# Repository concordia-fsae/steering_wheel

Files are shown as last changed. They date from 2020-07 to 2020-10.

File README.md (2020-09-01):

### This code now has Travis CI setup for continuous integration testing!
Current build status: 

# Setup Instructions
  1. Setup PlatformIO in IDE of choice (i.e. VSCode)
  2. Navigate to PlatformIO install directory (usually User_folder/.platformio)
  3. Enter `packages` directory and rename `framework-arduinoststm32-maple` to `framework-arduinoststm32-maple-bak`
  4. Clone [Roger Clark's repo](https://github.com/rogerclarkmelbourne/Arduino_STM32) into the packages directory (`git clone https://github.com/rogerclarkmelbourne/Arduino_STM32.git framework-arduinoststm32-maple`)
  5. Copy `platformio-build-stm32f4.py` and `platformio-build-stm32f1.py` from `framework-arduinoststm32-maple-bak/tools` to `framework-arduinoststm32-maple/tools`
  6. Compile successfully (hopefully)

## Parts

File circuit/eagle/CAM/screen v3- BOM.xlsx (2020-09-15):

Items | Part | Part number | Value | Quantity needed | Quantity bought | Unit price | Total Price
1 | Crystal | Q1 | 8MHz | 1 | -
2 | Capacitor | C3, C2 | 22PF | 2 | -
3 | Capacitor | C4 | 0.1uF | 1 | -
4 | Resisor | R2 | 10K | 1 | -
5 | Resisor | R3 | 120R | 1 | -
6 | canbus module | MCP2515-I/SO | n/a | 1 | -
7 |  | TJA1050 | n/a | 1 | -
8 | screen | NHD-4.3RTP | n/a | 1 | -
9 | JST connector | JST-XH-05-PACKAGE-ROUND-PAD | 5 pin CNCT | 1 | -
10 | stm 32 | stm32 | n/a | 1 | -
11 | JST connector | JST-XH-05-PACKAGE-ROUND-PAD | 5 pin CNCT | 1 | -
12 | LED | WS2812B_THT_ROUND |  | 16 | -
13

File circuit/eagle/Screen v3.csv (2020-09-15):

Part | Value | Device | Package | Description | AVAILABILITY | DESCRIPTION | MF | MP | MPN | OC_FARNELL | OC_NEWARK | PACKAGE | PRICE | SPICEPREFIX
BTN3 |  | SMD5 | SMD2,54-5,08 | SMD PAD
BTN4 |  | SMD5 | SMD2,54-5,08 | SMD PAD
BTN5 |  | SMD5 | SMD2,54-5,08 | SMD PAD
C2 | 22PF | C-EUC0805 | C0805 | CAPACITOR, European symbol |  |  |  |  |  |  |  |  |  | C
C3 | 22PF | C-EUC0805 | C0805 | CAPACITOR, European symbol |  |  |  |  |  |  |  |  |  | C
C4 | 0.1uF | C-EUC0805 | C0805 | CAPACITOR, European symbol |  |  |  |  |  |  |  |  |  | C
CANH |  | SMD5 | SMD2,54-5,08 | SMD PAD
CANL |  | SMD5 | SMD2,54-5,08 | SMD PAD
CSMCP |  | SMD5 | SMD2,54-5,08 | SMD PAD
DIN |  | SMD5 | SMD2,54-5,08 | SMD PAD
GND |  | SMD5 | SMD2,54-5,08 | SMD PAD
GND@1 |  | SMD5 | SMD2,54-5,08 | SMD PAD
GND@2 |  | SMD5 | SMD2,54-5,08 | SMD PAD
GND@3 | val\ | SMD5 | SMD2,54-5,08 | SMD PAD
MCPINT |  | SMD5 | SMD2,54-5,08 | SMD PAD
MISO |  | SMD5 | SMD2,54-5,08 | SMD PAD
MOSI |  | SMD5 | SMD2,54-5,08 | SMD PAD
Q1 | 8MHz | CRYSTALHC49S | HC49/S | CRYSTAL |  |  |  |  |  | 1667008 | unknown
R2 | 10K | R-EU_M0805 | M0805 | RESISTOR, European symbol |  |  |  |  |  |  |  |  |  | R
R3 | 120R | R-EU_M0805 | M0805 | RESISTOR, European symbol |  |  |  |  |  |  |  |  |  | R
RENC00 |  | SMD5 | SMD2,54-5,08 | SMD PAD
RENC0GND |  | SMD5 | SMD2,54-5,08 | SMD PAD
RENC01 |  | SMD5 | SMD2,54-5,08 | SMD PAD
RENC1GND |  | SMD5 | SMD2,54-5,08 | SMD PAD
RENC10 |  | SMD5 | SMD2,54-5,08 | SMD PAD
RENC11 |  | SMD5 | SMD2,54-5,08 | SMD PAD
SCK |  | SMD5 | SMD2,54-5,08 | SMD PAD
SCREEN | NHD-4.3RTP | NHD-4.3RTP | NHD-4.3RTP | Arduino R3 Footprint with SPI header
SW1 |  | SMD5 | SMD2,54-5,08 | SMD PAD
SW2 |  | SMD5 | SMD2,54-5,08 | SMD PAD
SW4 |  | SMD5 | SMD2,54-5,08 | SMD PAD
SW5 |  | SMD5 | SMD2,54-5,08 | SMD PAD
U$1 |  | STM32F103C8T6DIP40 | STM32
U$2 | MCP2515-I/SO | MCP2515-I/SO | SOIC127P1034X264-18N | CAN Controller | Unavailable | MCP2515 Series 5.5 V 1 Mb/s Stand Alone SPI Interface CAN Controller- SOIC-18 | Microchip | MCP2515-I/SO |  |  |  | SOIC-18 Microchip | None
U1 | TJA1050 | TJA1050 | SOT96-1 | High speed CAN transceiver | Unavailable |  | NXP Semiconductors | TJA1050 |  |  |  | None | None
VCCIN |  | SMD5 | SMD2,54-5,08 | SMD PAD
VCCLEDS |  | SMD5 | SMD2,54-5,08 | SMD PAD
VCCMCP |  | SMD5 | SMD2,54-5,08 | SMD PAD
X1 | 5 pin cnt | JST-XH-05-PIN-ROUND-PAD | JST-XH-05-PACKAGE-ROUND-PAD | JST XH Connector 2 Pin

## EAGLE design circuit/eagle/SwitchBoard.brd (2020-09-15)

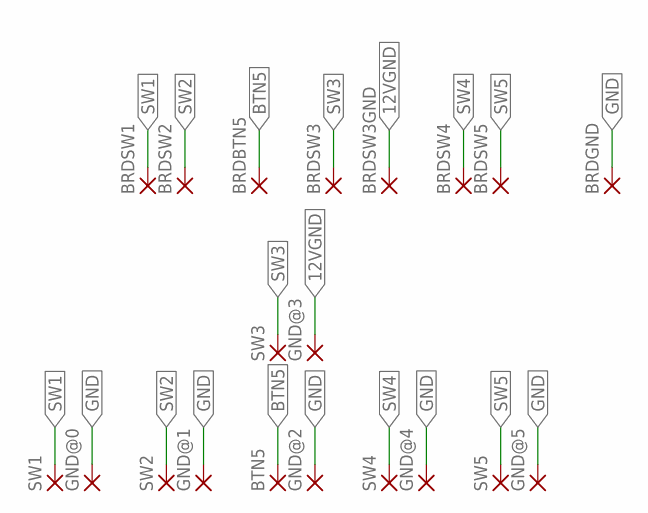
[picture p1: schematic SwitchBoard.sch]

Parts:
BRDBTN5: SMD5; SMD2,54-5,08
BRDGND: SMD5; SMD2,54-5,08
BRDSW1, BRDSW2, BRDSW3, BRDSW3GND, BRDSW4, BRDSW5: SMD5; SMD2,54-5,08
BTN5: SMD5; SMD2,54-5,08
GND@0, GND@1, GND@2, GND@3, GND@4, GND@5: SMD5; SMD2,54-5,08
SW1, SW2, SW3, SW4, SW5: SMD5; SMD2,54-5,08

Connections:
12VGND: BRDSW3GND.1, GND@3.1
BTN5: BRDBTN5.1, BTN5.1
GND: BRDGND.1, GND@0.1, GND@1.1, GND@2.1, GND@4.1, GND@5.1
SW1: BRDSW1.1, SW1.1
SW2: BRDSW2.1, SW2.1
SW3: BRDSW3.1, SW3.1
SW4: BRDSW4.1, SW4.1
SW5: BRDSW5.1, SW5.1

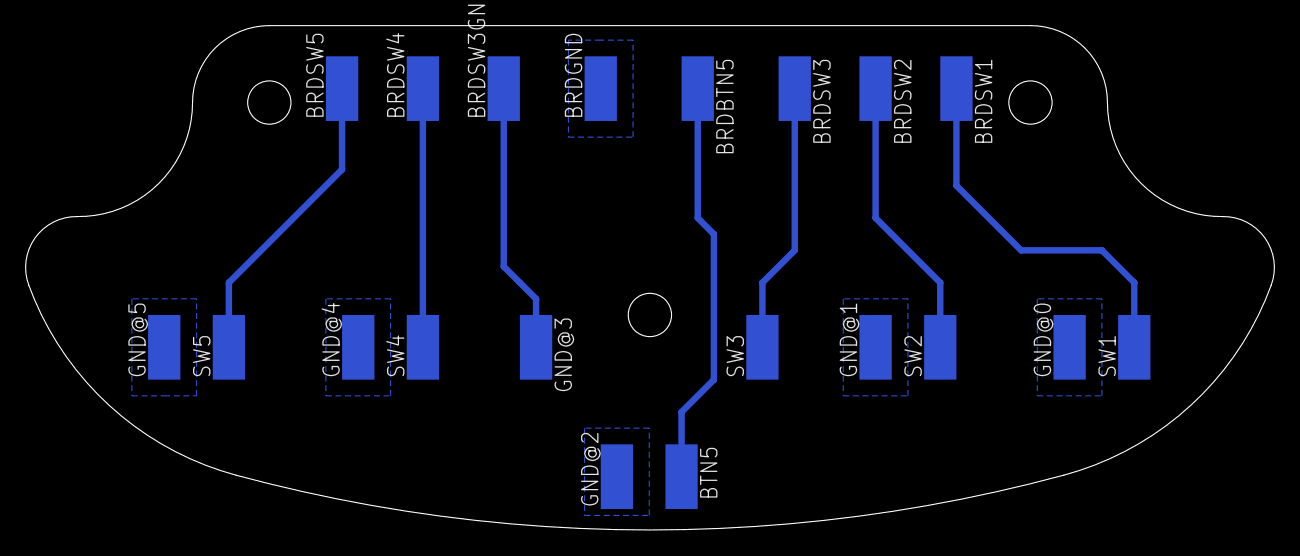
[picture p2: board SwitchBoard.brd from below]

Board: 2 copper layers, 98.1 x 39.6 mm, 20 parts (20 on the bottom side), 8 nets.

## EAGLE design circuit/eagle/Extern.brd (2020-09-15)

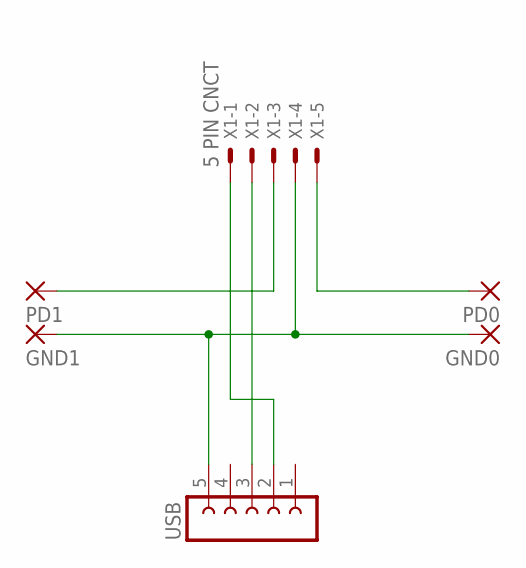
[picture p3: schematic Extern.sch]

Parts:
GND0, GND1: SMD5; SMD2,54-5,08
PD0, PD1: SMD5; SMD2,54-5,08
USB: FE05-1
X1: 5 PIN CNCT; JST-XH-05-PACKAGE-ROUND-PAD

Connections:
D+: USB.3, X1.2
D-: USB.2, X1.1
GND: GND0.1, GND1.1, USB.5, X1.4
unnamed: PD0.1, X1.5
PD1: PD1.1, X1.3

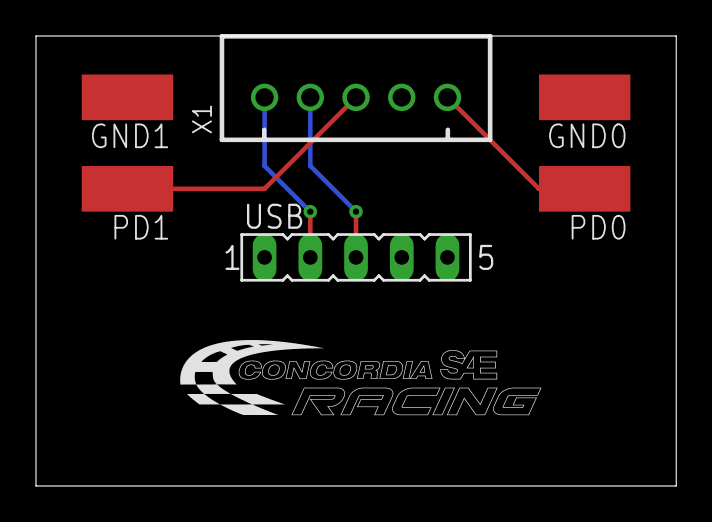
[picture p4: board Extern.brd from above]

Board: 2 copper layers, 35.6 x 25.0 mm, 6 parts (0 on the bottom side), 5 nets.

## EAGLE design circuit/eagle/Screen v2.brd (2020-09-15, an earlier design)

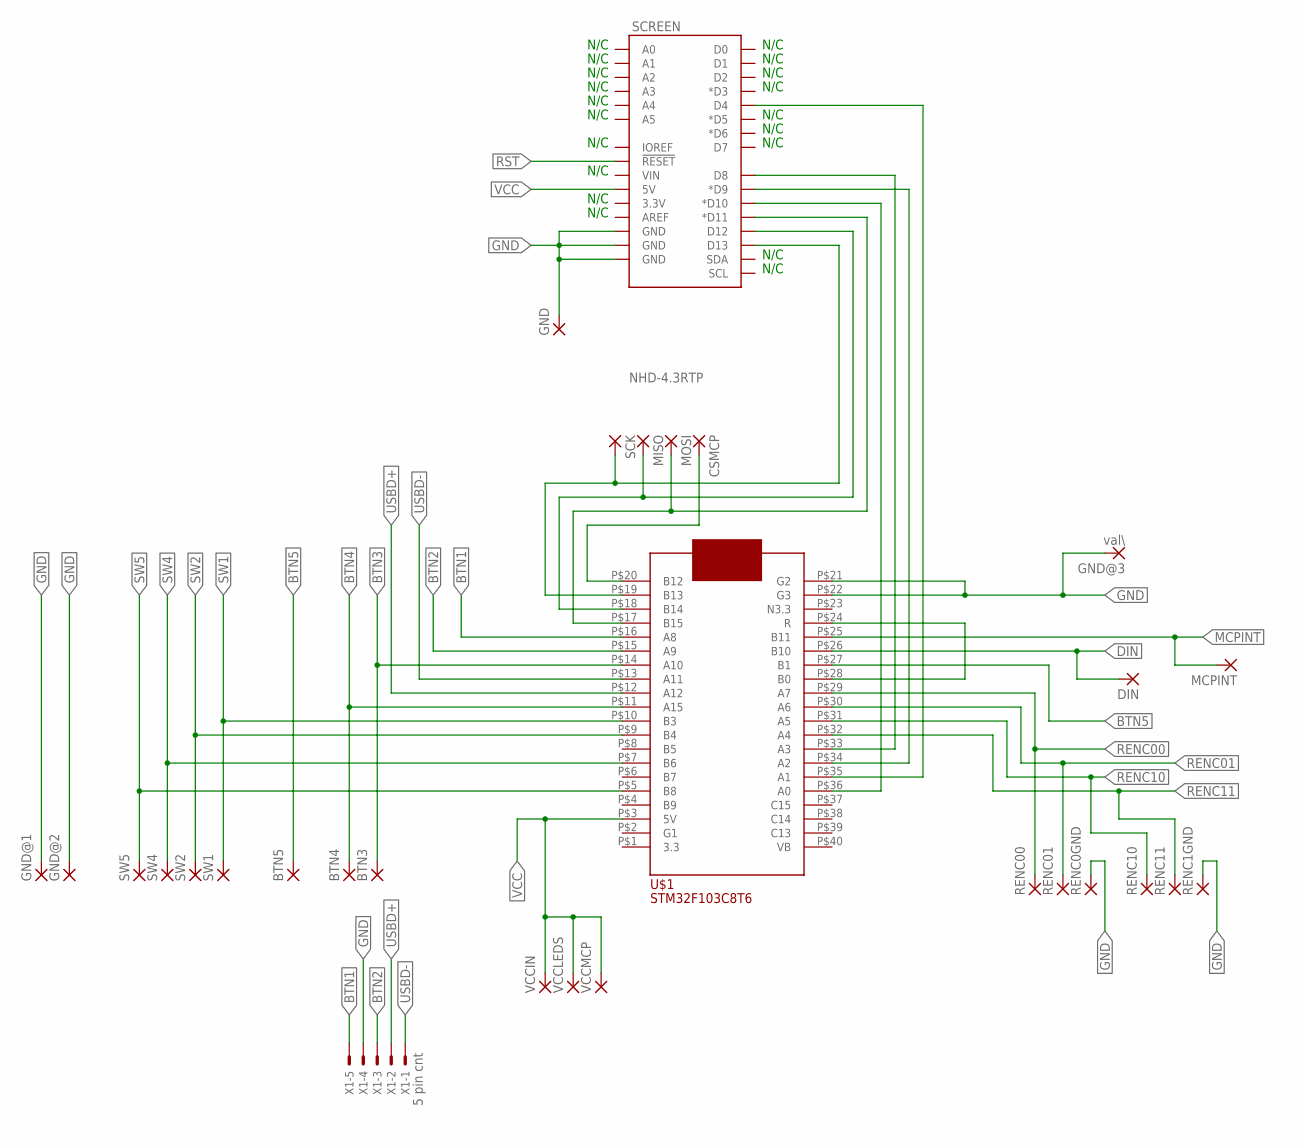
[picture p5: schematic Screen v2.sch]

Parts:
BTN3, BTN4, BTN5: SMD5; SMD2,54-5,08
CSMCP: SMD5; SMD2,54-5,08
DIN: SMD5; SMD2,54-5,08
GND: SMD5; SMD2,54-5,08
GND@1, GND@2: SMD5; SMD2,54-5,08
GND@3: val\; SMD2,54-5,08
MCPINT: SMD5; SMD2,54-5,08
MISO: SMD5; SMD2,54-5,08
MOSI: SMD5; SMD2,54-5,08
RENC00, RENC0GND, RENC01, RENC1GND, RENC10, RENC11: SMD5; SMD2,54-5,08
SCK: SMD5; SMD2,54-5,08
SCREEN: NHD-4.3RTP
SW1, SW2, SW4, SW5: SMD5; SMD2,54-5,08
U$1: STM32F103C8T6DIP40; STM32
VCCIN: SMD5; SMD2,54-5,08
VCCLEDS: SMD5; SMD2,54-5,08
VCCMCP: SMD5; SMD2,54-5,08
X1: 5 pin cnt; JST-XH-05-PACKAGE-ROUND-PAD

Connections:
BTN1: U$1.P$16 (A8), X1.5
BTN2: U$1.P$15 (A9), X1.3
BTN3: BTN3.1, U$1.P$14 (A10)
BTN4: BTN4.1, U$1.P$11 (A15)
BTN5: BTN5.1, U$1.P$27 (B1)
CSMCP: CSMCP.1, U$1.P$20 (B12)
CS_SCREEN: SCREEN.D10 (*D10), U$1.P$36 (A0)
DIN: DIN.1, U$1.P$26 (B10)
GND: GND.1, GND@1.1, GND@2.1, GND@3.1, RENC0GND.1, RENC1GND.1, SCREEN.GND@1 (GND), SCREEN.GND@2 (GND), SCREEN.GND@3 (GND), U$1.P$21 (G2), U$1.P$22 (G3), X1.4
MCPINT: MCPINT.1, U$1.P$25 (B11)
MISO: MISO.1, SCREEN.D12, U$1.P$18 (B14)
MOSI: MOSI.1, SCREEN.D11 (*D11), U$1.P$17 (B15)
unnamed: SCREEN.D4, U$1.P$35 (A1)
unnamed: SCREEN.D9 (*D9), U$1.P$34 (A2)
unnamed: SCREEN.D8, U$1.P$33 (A3)
unnamed: U$1.P$24 (R), U$1.P$28 (B0)
RENC00: RENC00.1, U$1.P$29 (A7)
RENC01: RENC01.1, U$1.P$30 (A6)
RENC10: RENC10.1, U$1.P$31 (A5)
RENC11: RENC11.1, U$1.P$32 (A4)
RST: SCREEN.RESET@1 (!RESET!)
SCK: SCK.1, SCREEN.D13, U$1.P$19 (B13)
SW1: SW1.1, U$1.P$10 (B3)
SW2: SW2.1, U$1.P$9 (B4)
SW4: SW4.1, U$1.P$7 (B6)
SW5: SW5.1, U$1.P$5 (B8)
USBD+: U$1.P$12 (A12), X1.2
USBD-: U$1.P$13 (A11), X1.1
VCC: SCREEN.5V, U$1.P$3 (5V), VCCIN.1, VCCLEDS.1, VCCMCP.1

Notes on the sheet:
N/C

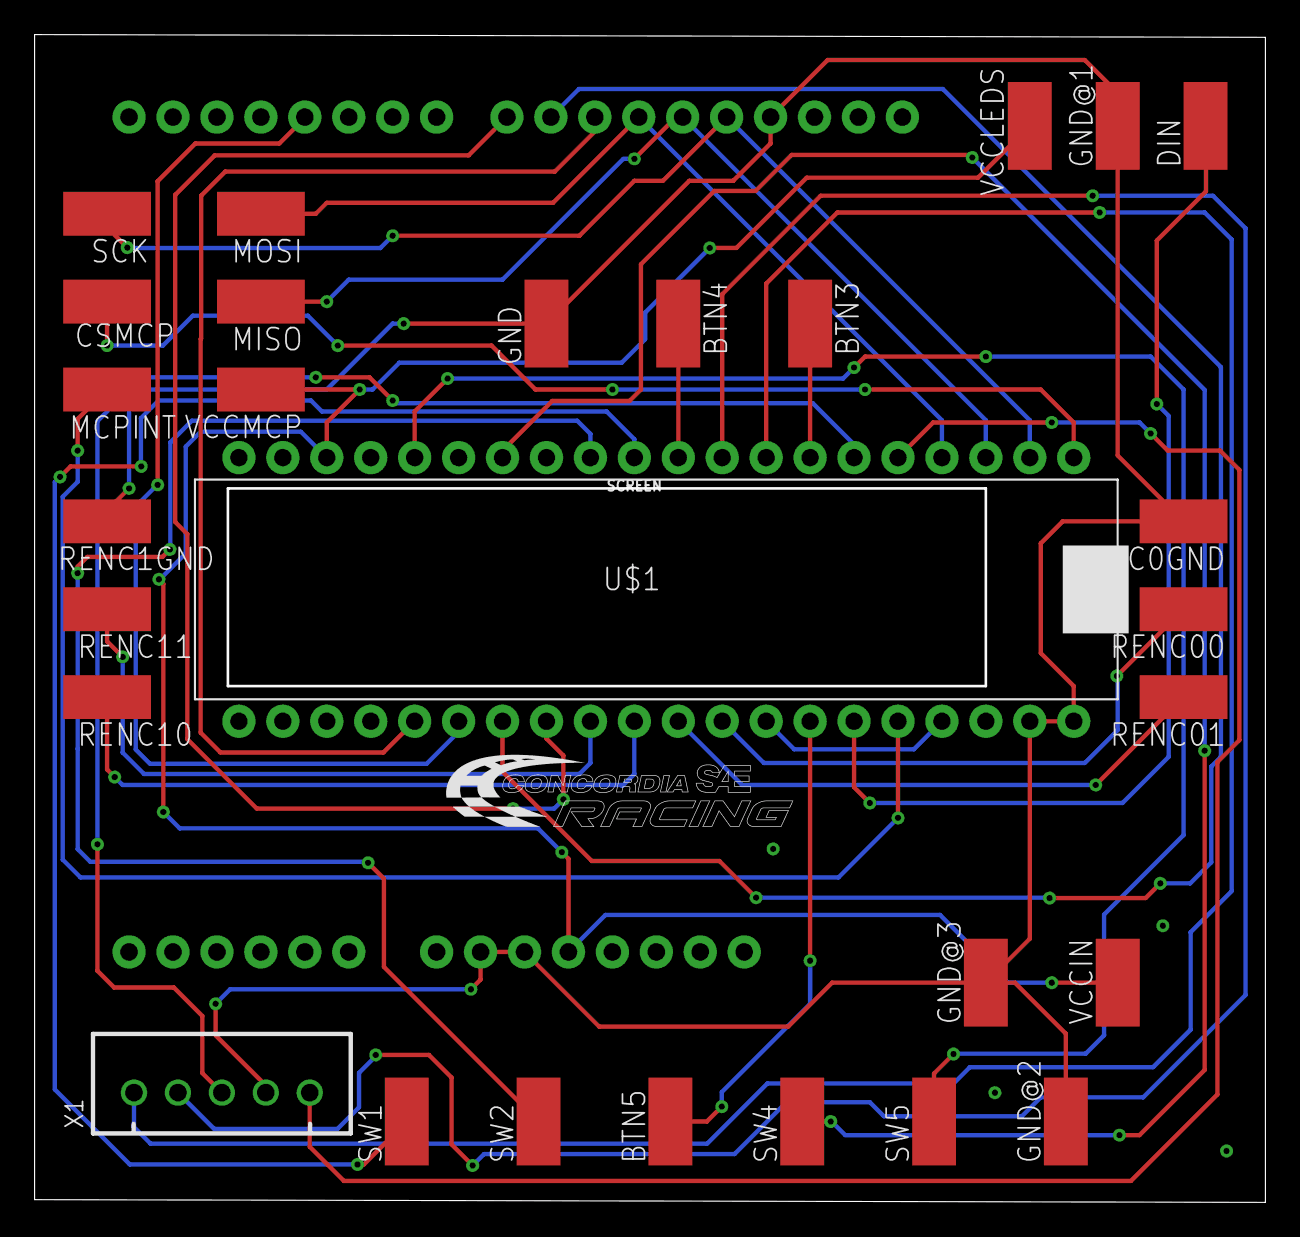
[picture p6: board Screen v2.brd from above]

Board: 2 copper layers, 71.2 x 67.5 mm, 29 parts (0 on the bottom side), 28 nets.

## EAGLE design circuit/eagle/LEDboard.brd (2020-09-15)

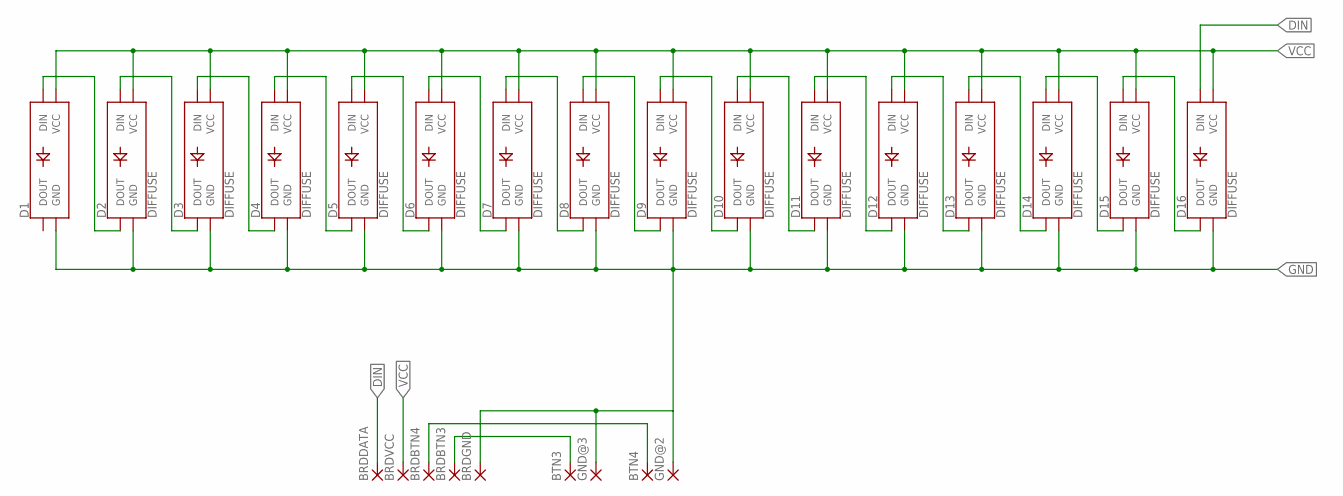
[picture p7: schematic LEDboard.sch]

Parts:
BRDBTN3, BRDBTN4: SMD5; SMD2,54-5,08
BRDDATA: SMD5; SMD2,54-5,08
BRDGND: SMD5; SMD2,54-5,08
BRDVCC: SMD5; SMD2,54-5,08
BTN3, BTN4: SMD5; SMD2,54-5,08
D1: WS2812B_THT_ROUNDDIFFUSE; WS2812B_THT_ROUND
D2, D3, D4, D5, D6, D7, D8, D9, D10, D11, D12, D13, D14, D15, D16: DIFFUSE; WS2812B_THT_ROUND
GND@2, GND@3: SMD5; SMD2,54-5,08

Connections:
BTN3: BRDBTN3.1, BTN3.1
BTN4: BRDBTN4.1, BTN4.1
DIN: BRDDATA.1, D16.1 (DIN)
GND: BRDGND.1, D1.3 (GND), D2.3 (GND), D3.3 (GND), D4.3 (GND), D5.3 (GND), D6.3 (GND), D7.3 (GND), D8.3 (GND), D9.3 (GND), D10.3 (GND), D11.3 (GND), D12.3 (GND), D13.3 (GND), D14.3 (GND), D15.3 (GND), D16.3 (GND), GND@2.1, GND@3.1
unnamed: D15.1 (DIN), D16.4 (DOUT)
unnamed: D14.1 (DIN), D15.4 (DOUT)
unnamed: D13.1 (DIN), D14.4 (DOUT)
unnamed: D12.1 (DIN), D13.4 (DOUT)
unnamed: D11.1 (DIN), D12.4 (DOUT)
unnamed: D10.1 (DIN), D11.4 (DOUT)
unnamed: D9.1 (DIN), D10.4 (DOUT)
unnamed: D8.1 (DIN), D9.4 (DOUT)
unnamed: D7.1 (DIN), D8.4 (DOUT)
unnamed: D6.1 (DIN), D7.4 (DOUT)
unnamed: D5.1 (DIN), D6.4 (DOUT)
unnamed: D4.1 (DIN), D5.4 (DOUT)
unnamed: D3.1 (DIN), D4.4 (DOUT)
unnamed: D2.1 (DIN), D3.4 (DOUT)
unnamed: D1.1 (DIN), D2.4 (DOUT)
VCC: BRDVCC.1, D1.2 (VCC), D2.2 (VCC), D3.2 (VCC), D4.2 (VCC), D5.2 (VCC), D6.2 (VCC), D7.2 (VCC), D8.2 (VCC), D9.2 (VCC), D10.2 (VCC), D11.2 (VCC), D12.2 (VCC), D13.2 (VCC), D14.2 (VCC), D15.2 (VCC), D16.2 (VCC)

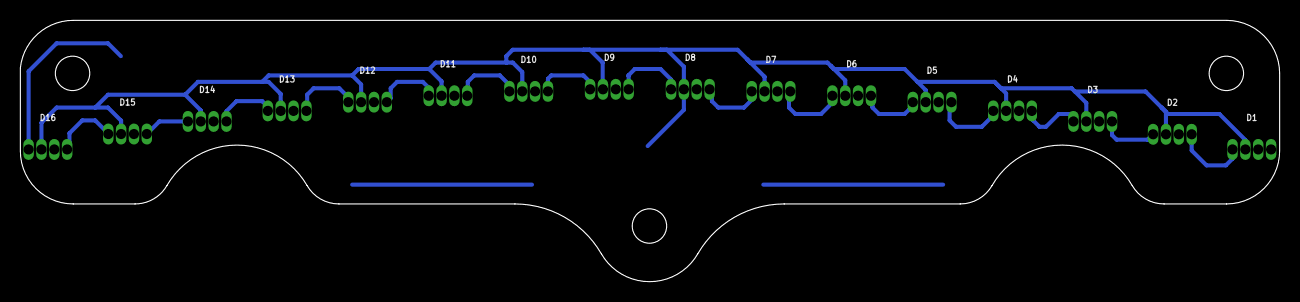
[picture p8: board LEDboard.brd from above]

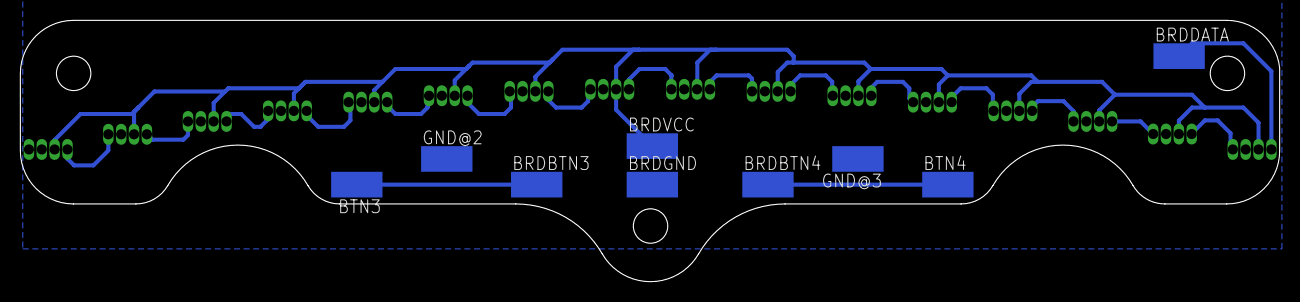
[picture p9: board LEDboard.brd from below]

Board: 2 copper layers, 124.5 x 25.8 mm, 25 parts (9 on the bottom side), 20 nets.

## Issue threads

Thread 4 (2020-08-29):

use direct port access for button status

rickyelopez, 2020-08-29:
Rather than calling digitalRead over and over, pull the data for the whole port and filter out unnecessary values

rickyelopez, 2020-09-01:
issue handled in #10 , closing for now, might re-open once we have access to the cage and can actually test this

Closed 2020-09-01.

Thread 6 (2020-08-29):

implement timer class instead of always comparing numbers

rickyelopez, 2020-08-29:
instead of comparing current time to history over and over, create a timer class that can be queried and updated.

rickyelopez, 2020-09-05:
on hold while I investigate potentially using FreeRTOS

Closed 2020-09-05.

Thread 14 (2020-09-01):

store calibration info in eeprom && make calibration accessible from UI

rickyelopez, 2020-09-01:
Right now all the touchscreen calibration constants are hard-coded and not changeable through software.

1. Store the constants associated with touchscreen calibration in EEPROM
    - can initialize these values with the ones that are currently hard-coded
    - can re-initialize (i.e. if eeprom is ever found to be empty) with the hard-coded values
2. Clean up the calibration routine (read: make the calibration routine actually make sense)
    - make this method callable through code
    - add button to diag page that launches calibration
    - make this method actually store the constants in eeprom
    - add a `#define` and associated method that clears the calibration constants from the eeprom (in case someone badly calibrates the screen and we need to reset it

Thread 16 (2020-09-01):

[potential bug] with displaying common status indicators

rickyelopez, 2020-09-01:
lines 304-323 in screen.h:

```
	col = (tl) ? 0x00FF00 : 0xFFFFFF;
	FTImpl.ColorRGB(col);
	FTImpl.Vertex2ii(20, 35, 1, 0);

	col = (tl) ? 0x00FF00 : 0xFFFFFF;
	FTImpl.ColorRGB(col);
	FTImpl.Vertex2ii(445, 35, 1, 0);

	col = (tl) ? 0x00FF00 : 0xFFFFFF;
	FTImpl.ColorRGB(col);
	FTImpl.Vertex2ii(150, 255, 1, 0);

	col = (tl) ? 0x00FF00 : 0xFFFFFF;
	FTImpl.ColorRGB(col);
	FTImpl.Vertex2ii(210, 255, 1, 0);

	col = (tl) ? 0x00FF00 : 0xFFFFFF;
```

each of these references `tl` but I think each of them should reference a different status var. Can someone check this and see if maybe I'm being silly?

If I'm right, then that means that this codebase is not actually the most recent steering wheel code. No idea where any more recent code might be though, so next time we go out driving we'll have to re-validate that all the functions work :/

rickyelopez, 2020-09-05:
confirmed bug, easy fix

Closed 2020-09-06.

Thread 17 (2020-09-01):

[potential bug] double-check debouncing code for remote-start activation

rickyelopez, 2020-09-01:
in the get_inputs() function, the code that checks if both the top left and top right buttons are pressed is:
```
	if(tl && tr){
		tr_deb = (!tr_deb) ? c_time : tr_deb;
		if(c_time - tr_deb > 500){

			tr_deb = 0;
			remote_start = true;
		}
		tr = tl = false;

	} else {
		remote_start = 0;
		tr_deb = 0;
	}
```

Once we have access to the car and the steering wheel, need to check that this actually works properly.

Closed 2020-09-06.

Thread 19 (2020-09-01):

redesign shifter paddles to use the magnets as buttons

rickyelopez, 2020-09-01:
Instead of having the shifter paddle press down on a little button, attach some wires to the magnets on the paddle and on the paddle base. Then, when the magnets are separated the circuit will be broken, which we can measure! Use that event to trigger shifts.

This change should mean that the entire shifter package can be made more compact and **much** simpler. Plus, assembly will be easier.

- [ ] Add channels for wires to pass through to get to magnets
- [ ] Figure out how to securely connect wires to magents - can we solder? Might break magnets
- [ ] Test changes

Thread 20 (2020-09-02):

fork seeed canbus library and implement as git submodule

rickyelopez, 2020-09-02:
I used [this](https://github.com/Seeed-Studio/CAN_BUS_Shield) library to implement the MCP2515. I had to modify it slightly to get it to work for our use case. Thus, it hasn't been updated from source in literally years. The source has changed quite a bit since then, so it would be nice to rebase to the new code and validate that everything still works. If the modification that I originally made is still necessary, the seeed repo should be forked to our org and modified. Either way it should be re-implemented using a git submodule so that we can keep it up to date.

- [ ] **independently** (i.e. not using the steering wheel, lest we seriously break something) validate whether the un-modified seeed codebase works for can communication between the motec and stm32/esp32.
    - [ ] if it doesn't work, fork the seeed repo into our organization
    - [ ] re-implement the modification I had originally made (talk to @rickyelopez about this if necessary)
- [ ] either way, re-implement into this repo using [git submodules](https://git-scm.com/book/en/v2/Git-Tools-Submodules) so that we can easily update in the future

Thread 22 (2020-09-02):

fork newhaven FT800 library and reimplement as git submodule

rickyelopez, 2020-09-02:
The [Newhaven FT800](https://github.com/NewhavenDisplay/FTDI_FT800) library required a few modifications to work on the stm32 (fortunately, I believe most of these were made obvious by compile-time errors, so should be easy to hunt down).

- [ ] Check whether the newest version of the repo works on the steering wheel (be warned, modifications will be necessary)
    - [ ] if it doesn't work, make it work
- [ ] Fork the the newhaven repo into our organization and modify as necessary
- [ ] Re-implement into this repo as a [git submodule](https://git-scm.com/book/en/v2/Git-Tools-Submodules)

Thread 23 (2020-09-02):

store all data from motec in an struct

rickyelopez, 2020-09-02:
Currently everything is just stored in global vars. Convert to struct.

- [x] Create an struct with the all the relevant data
    - [x] double check data sizes while doing this

rickyelopez, 2020-09-02:
Tasks in the issue are complete but the work I did has brought some new tasks to light:

-[ ] Handle the conversion of voltage float to two integers better; read: pure function

I will add more tasks as I think of them

Closed 2020-09-04.

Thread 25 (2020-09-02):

try using interrupts to trigger can reading again

rickyelopez, 2020-09-02:
I tried this once upon a time but it didn't work very well (read: at all). In theory we can save some cycle time by not checking CAN unless we know there's a message. The MCP2515 supports sending an interrupt when a message has been received, and I wired up that pin even though I didn't intend to use it.

- [ ] Create ISR that sets a "message received" flag
- [ ] Every cycle, check that flag. If true, process message

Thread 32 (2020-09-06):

add launch control "profiles" to the launch page

rickyelopez, 2020-09-06:
Add some buttons that switch between profiles. Labels would also be good. Make the profiles modifiable from the steering wheel. We can have, for example, a "Cold Weather" profile or "Wet Track" profile, etc. Should make on-the-fly tuning a lot faster if we have base values to start from.

- [ ] Add profile buttons to the launch page
- [ ] Add a label to show what profile is currently selected
- [ ] Make the profiles actually affect the launch values

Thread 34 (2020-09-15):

re-implement circuit in altium

rickyelopez, 2020-09-15:
I originally made this circuit in Eagle, time to move up to Altium

- [ ] Fully implement Newhaven schematic on PCB using the FT810 instead of FT800
- [ ] Switch to ESP32????
- [ ] Try to put all switch inputs onto the same port for register access
- [ ] Try to switch the screen to a different SPI Bus
- [ ] Look into changing away from MCP2515 or at least TJA1050

rickyelopez, 2020-12-31:
I decided against putting the circuit in this repo. See the `circuits` repo for the steering wheel circuit, and eventually any other circuits as well.

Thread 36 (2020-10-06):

redefine c_time so it doesn't use millis()

rickyelopez, 2020-10-06:
Even though it turns out the `millis()` function is actually really efficient, we can do even better! Redefine c_time as an alias to systick_uptime_millis and then we never need to update the value again.

- [x] redefine c_time as alias for systick_uptime_millis
- [x] remove all calls to millis()
- [ ] validate that everything still works

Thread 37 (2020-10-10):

[bug] spi frequency too fast for ft800

rickyelopez, 2020-10-10:
I had accidentally fixed this a few years ago through sheer luck. Fixing for realsies now by setting the SPI Clock Divider to actually reduce the SPI speed below 30 MHz, which is the max that the ft800 can handle.

Closed 2020-10-17.

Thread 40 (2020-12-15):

implement watchdog

rickyelopez, 2020-12-15:
Apparently the stm32f013c8 has dual internal watchdog? Still vulnerable to silicon failure, but might be helpful none the less.

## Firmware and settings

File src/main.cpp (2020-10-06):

#include "main.h"

ShiftLights shift_lights = ShiftLights(kSLPin, kSLCount, kSLBrightness);
SPIClass SPI_2(2);

// define global time tracker
volatile uint32_t &c_time = systick_uptime_millis;

void setup(){
	Serial.begin(115200);
	
/* DEBUG CODE
	// wait for computer to connect to serial before continuing
	while(Serial.read() <= 0);
	Serial.println("Serial connected.");

// DEBUG CAN CONNECTION
	// verify connection to can bus module
	while(!(CAN_OK == CAN.begin(CAN_1000KBPS, PB12))){
		Serial.print("MCP2515 Connection Failed, retrying ");
		Serial.println(CAN.begin(CAN_1000KBPS, PB12));
		delay(100);
	}
	Serial.println("MCP2515 Connection Successfull!");
// */
	// define all input pins
	uint8_t inputs [13] = {PB3, PB4, PB6, PB8, PA8, PA9, PA10, PA15, PB1, PA7, PA6, PA5, PA4};

	// initialize all pins to input pullup
	for(auto &input : inputs){
		pinMode(input, INPUT_PULLUP);
	}

	// initnialize reset pin and default to high so we don't get stuck in a reset loop
	pinMode(RST, OUTPUT);
	digitalWrite(RST, HIGH);
	
	// start up the screen
	boot_display();

	// run the shift light startup sequence
	shift_lights.LedStartup();

/* Uncomment when calibrating touch screen
	for(int i=0; i<6; i++)
	{
		Serial.print(touch_matrix[i]); Serial.print(" ");
	}
	Serial.println();
*/

	if(!(CAN_OK == CAN.begin(CAN_1000KBPS, MCP_CS))){
		warning.current = 0;
	}

	/*
	 * At this point we know that all systems have booted and everything is good to go
	*/

	// not sure if this even does anything
	CAN.init_Filt(0, 0, recv_id);
}

void loop(){
	digitalWrite(RST, !diag_rst);

	if(c_time - l_time_50 >= fifty_hz){		// send/recv data from Motec at 50 Hz
		l_time_50 = c_time;
		// code for sending to Motec over CAN
		uint8_t status1, status2;
		get_inputs(status1, status2);
		uint8_t buff[4] = {status1, status2, veh.launch_cnf.th_speed, veh.launch_cnf.rpm};
		CAN.sendMsgBuf(transmit_ID, 0, 4, buff);

		// check for CAN Comms error and process any waiting CAN messages
		if(CAN_MSGAVAIL == CAN.checkReceive()){
			can_receive();
			last_can_update = c_time;
			warning.current = -1;
		}
		else if((c_time - last_can_update > can_timeout)){
			warning.current = 0;
		}

		shift_lights.Update(veh.gear, veh.rpm);
	}

	if(c_time - l_time_10 > ten_hz){
		diag_shift = 0;
		uint16_t ts_btn = ts_btn_pressed();

		int colors [2] = {0x0, 0x00FF00};
		switch(ts_btn){
		case 0:
			diag_fuel_deb.Reset();
			launch_rpm_minus.Reset();
			launch_rpm_plus.Reset();
			launch_thresh_minus.Reset();
			launch_thresh_plus.Reset();
		// no 0th button
			break;
		case 1:
		// case 1, shift light diagnostics
			diag_shift = 1;
			shift_lights.SetAllColor(colors[diag_shift]);
			break;
		case 2:
		// case 2, turn on fuel pump
			if(diag_fuel_deb.Deb()){
				diag_fuel_st = !diag_fuel_st;
			}
			break;
		case 3:
		// case 3, reset MCU
			FTImpl.Clear(1,1,1);
			diag_rst = 1;
			break;
		case 4:
			if(launch_rpm_minus.Deb()){
				if(veh.launch_cnf.rpm > 20){veh.launch_cnf.rpm -= 2;}
			}
			break;
		case 5:
			if(launch_rpm_plus.Deb()){
				if(veh.launch_cnf.rpm < 80){veh.launch_cnf.rpm += 2;}
			}
			break;
		case 6:
			if(launch_thresh_minus.Deb()){
				if(veh.launch_cnf.th_speed > 15){veh.launch_cnf.th_speed -= 5;}
			}
			break;
		case 7:
			if(launch_thresh_plus.Deb()){
				if(veh.launch_cnf.th_speed < 60){veh.launch_cnf.th_speed += 5;}
			}
			break;
		default:
			break;
		}
	}

	if(check_display()){
		FTImpl.DLStart();

		if(veh.io.sw3){
			diag_display(diag_shift, diag_fuel_st, diag_rst);
		} else if(veh.io.sw1){
			launch_display();
		} else {
			main_display();
		}

		if((warning.current != -1) && !(warning.dismissed & (warning.current + 1)) && !veh.io.sw3){
			error_overlay();
		}

		FTImpl.DLEnd();
		FTImpl.Finish();
	} else {
		FTImpl.DisplayOff();
		FTImpl.Exit();
	}
}

void get_inputs(uint8_t &status1, uint8_t &status2){
	uint32_t portb = GPIOB->regs->IDR;
	uint32_t porta = GPIOA->regs->IDR;

	veh.io.mid		=	!(portb & 0b10);
	veh.io.sw1		=	!(portb & 0b100000000);
	veh.io.sw2		=	!(portb & 0b1000000);
	veh.io.sw3		=	!(portb & 0b10000);
	veh.io.sw4		=	!(portb & 0b1000);
	veh.io.pl		=	!(porta & 0b100000000);
	veh.io.pr		=	!(porta & 0b1000000000);
	veh.io.tl		=	!(porta & 0b10000000000);
	veh.io.tr		=	!(porta & 0b1000000000000000);


	if(veh.io.tl && veh.io.tr){
		// set the remote start bit to true if both the top buttons have
		// been held for more than 500 ms, otherwise set it to false
		// reset when one of the buttons is released
		veh.io.remote_start = remote_start.Deb();
		veh.io.tr = veh.io.tl = false;
	} else {
		veh.io.remote_start = false;
		remote_start.Reset();
	}

	// dismiss the current warning if either tl or tr is pressed, intercept their respective functions
	if((veh.io.tl || veh.io.tr) && warning.current != -1){
		if(!(warning.dismissed & (warning.current+1))){
			warning.dismissed = warning.dismissed | (warning.current+1);
			warning.current = -1;
			veh.io.tl = 0;
			veh.io.tr = 0;
		}
	}

	// un-dismiss the warnings if the middle button is pressed
	warning.dismissed = veh.io.mid ? 0 : warning.dismissed;

	// create the status bitfields
	status1 = 0;
	status2 = 0;

	status1 = status1
					| veh.io.sw1 
					| veh.io.sw2 << 1 
					| veh.io.sw3 << 2 
					| veh.io.sw4 << 3 
					| veh.io.tr << 4 
					| veh.io.tl << 5 
					| veh.io.pr << 6 
					| veh.io.pl << 7;

	status2 = status2
					| veh.io.mid
					| diag_fuel_st << 1
					| veh.io.remote_start << 2;
}

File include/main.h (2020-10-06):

#ifndef MAIN_H
#define MAIN_H

#include <Arduino.h>
#include <EEPROM.h>
#include <SPI.h>
#include <Wire.h>
#include <inttypes.h>
#include "VehicleData.h"
#include "shiftlights.h"
#include "canbus.h"
#include <FT_NHD_43RTP_SHIELD.h>
#include "screen.h"
#include "Debouncer.h"



// pin that is connected to rst
#define RST PB0


// TODO: replace all of this with a timer class
extern volatile uint32_t &c_time;
uint32_t l_time_50 = 0;		    // last time a 50Hz event occured
uint32_t l_time_10 = 0;		    // last time a 10Hz event occured
uint32_t l_time_5 = 0;			// last time a 5Hz event occured
uint32_t l_time_1 = 0;			// last time a 1Hz event occured


// constants for each refresh rate
uint16_t fifty_hz = 20;
uint16_t ten_hz = 100;
uint16_t five_hz = 200;
uint16_t one_hz = 1000;
// end todo


// debounce vars
Debouncer remote_start = Debouncer(500, 0);
Debouncer diag_fuel_deb = Debouncer(200, 500);
Debouncer launch_rpm_plus = Debouncer();
Debouncer launch_rpm_minus = Debouncer();
Debouncer launch_thresh_minus = Debouncer();
Debouncer launch_thresh_plus = Debouncer();

// end todo


// status vars
bool led_err_st = 0;
bool led_clear = 1;
bool diag_shift = 0;
bool diag_rst = 0;
bool diag_fuel_st = 0;

// Local Function Prototypes
void get_inputs(uint8_t&, uint8_t&);

// External Variables
//TODO move all CAN stuff out of main and then delete this variable
extern MCP_CAN CAN;
#endif // MAIN_H

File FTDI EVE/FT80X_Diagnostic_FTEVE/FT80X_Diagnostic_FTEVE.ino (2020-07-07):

#include <EEPROM.h>
#include <SPI.h>
#include <Wire.h>
#include <FT_VM800B35.h>

FT800IMPL_SPI FTImpl(FT_CS_PIN,FT_PDN_PIN,FT_INT_PIN);
void setup()
{
	FTImpl.Init(FT_DISPLAY_RESOLUTION);
	FTImpl.SetDisplayEnablePin(FT_DISPENABLE_PIN);
	FTImpl.SetAudioEnablePin(FT_AUDIOENABLE_PIN);
	FTImpl.DisplayOn();
	FTImpl.AudioOn();

	FTImpl.DLStart();
	FTImpl.Finish();
	FTImpl.DLStart();
	FTImpl.DLEnd();
	FTImpl.Finish();
}

void loop()
{
	FTImpl.DLStart();
	FTImpl.Cmd_Text(240, 32, 28, FT_OPT_CENTER, "Screen Diagnostics");
	
	
	FTImpl.Begin(FT_POINTS);
	FTImpl.PointSize(246);
	FTImpl.Tag(0);
	FTImpl.Vertex2ii(30, 150, 0, 0);
	FTImpl.Tag(1);
	FTImpl.Vertex2ii(30, 30, 0, 0);
	FTImpl.Tag(2);
	FTImpl.Vertex2ii(120, 245, 0, 0);
	FTImpl.Tag(3);
	FTImpl.Vertex2ii(180, 245, 0, 0);
	FTImpl.Tag(4);
	FTImpl.Vertex2ii(240, 245, 0, 0);
	FTImpl.Tag(5);
	FTImpl.Vertex2ii(300, 245, 0, 0);
	FTImpl.Tag(6);
	FTImpl.Vertex2ii(360, 245, 0, 0);
	FTImpl.Tag(7);
	FTImpl.Vertex2ii(450, 30, 0, 0);
	FTImpl.Tag(8);
	FTImpl.Vertex2ii(450, 150, 0, 0);
	FTImpl.Tag(9);
	FTImpl.PointSize(600);
	FTImpl.Vertex2ii(240, 145, 0, 0);
	FTImpl.End();
	
	FTImpl.Cmd_Text(240, 90, 28, FT_OPT_CENTER, "Shift Lights");
	FTImpl.Cmd_Text(65, 150, 28, FT_OPT_CENTER, "PL");
	FTImpl.Cmd_Text(65, 30, 28, FT_OPT_CENTER, "TR");
	FTImpl.Cmd_Text(120, 215, 28, FT_OPT_CENTER, "SW1");
	FTImpl.Cmd_Text(180, 215, 28, FT_OPT_CENTER, "SW2");
	FTImpl.Cmd_Text(240, 215, 28, FT_OPT_CENTER, "MID");
	FTImpl.Cmd_Text(300, 215, 28, FT_OPT_CENTER, "SW4");
	FTImpl.Cmd_Text(360, 215, 28, FT_OPT_CENTER, "SW5");
	FTImpl.Cmd_Text(415, 30, 28, FT_OPT_CENTER, "TR");
	FTImpl.Cmd_Text(415, 150, 28, FT_OPT_CENTER, "PR");
	FTImpl.DLEnd();
	FTImpl.Finish();
}

/* end of file */

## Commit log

2019-05-22 switched to platformio
2020-09-03 restructured all of the globals containing car info into structs, everything is now contained within the global. Also separated canbus.h into canbus.h + canbus.cpp. This issue should be closed for no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
    [main.cpp, main.h]
2020-09-04 got it to compile, the only real problem was the SPI was being defined somewhere in the FT800 headers when it shouldn't have been. Sorted by making that definition extern and moving the real definiti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
    [main.cpp, main.h]
2020-09-05 addresses #16, simple bug which has been fixed. I think pin B3 might be blown on my test setup because it's not tripping the wheel circumference flag but I can't find any code mistakes. Either way, i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
2020-09-05 implemented the debouncer class I added. Also modified it a bit for some extra functionality Fully replaced all references to other types of debouncing with references to this class, tested everythin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
    [main.cpp, main.h, shiftlights.cpp]
2020-09-15 Add existing circuit files
    [Extern.brd, Extern.sch, LEDboard.brd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]
